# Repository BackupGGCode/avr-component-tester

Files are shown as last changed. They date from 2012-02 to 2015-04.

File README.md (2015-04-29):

# AVR Component Tester #

### DESCRIPTION ###
We really liked the original project; so we are bringing it back as ACT. Mainly for ourselves but anyone interested is welcome to build there own.

It is an AVR Atmega based electronic components tester based on the original _AVR Transistor Tester by Markus Frejek_. Its a completely open project, feel free to use the content on this Google code page in any way you like; as long as it follows the same or stricter guidelines then the original.

At the moment there is not much different then the original; other then we took away the multi-language (we will keep the strings editable for anyone interested in changing the language themselves) and only changed a few small items. Thats only because we are still awaiting our latest PCBs which includes onboard ISP header, broken out UART, and broken out un-used pins for future functionality.

Only reason I made this page was to store our updates to a public SVN.

Also see my [readme](https://github.com/BackupGGCode/avr-component-tester/blob/master/README) file.

---

### ACKNOWLEDGE ###
_This is a project based on the original_

_AVR Transistor Tester_
_by Markus Frejek_
_http://www.mikrocontroller.net/articles/AVR-Transistortester_

---

&lt;brentbxr&gt;

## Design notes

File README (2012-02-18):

The firmware was specificly designed to on an Atmega328p but really; 
any 28pin atmega 8k and up will work; and as long as your utilizing 
winavr just make sure you include its IO header file; you should be 
able to upload the source no problem. Ensure to double check the 
pinout and make changes as needed.

At some point I will most likly include differnt pre-compiled files 
for multiple atmega's for the public, depending on if there is any 
demand at all. Most likly there will be none, as its really just a 
personal project.

I also have some left-over PCBs; so if your interested just contact
BrentBXR and I might be able to mail you one. As long as you promise 
to build it up, and enjoy it. I wont send somone a PCB just so they 
can have a PCB laying around...

Thanks -BrentBXR [@gmail]

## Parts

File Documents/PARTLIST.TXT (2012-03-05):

AVR Component Tester [v1.0]
SVN: http://code.google.com/p/avr-component-tester/
Project with BrentBXR and MickM

--------------------------------------------------------------------------------------
======================================================================================
--------------------------------------------------------------------------------------

Partlist
Exported from 2-6-2012-b (2).sch at 3/1/2012 9:00:39 PM

Part        Value          Device          Package       Library                 Sheet

9V-DC-IN                   PINHD-1X2       1X02          pinhead                 1
C1          100n           C-US025-030X050 C025-030X050  rcl                     1
C2          100nF          C-US025-030X050 C025-030X050  rcl                     1
C3          100n           C-US025-030X050 C025-030X050  rcl                     1
C4          100n           C-US025-030X050 C025-030X050  rcl                     1
C5          100n           C-US025-030X050 C025-030X050  rcl                     1
C6          100uF          CPOL-USE2-5     E2-5          rcl                     1
D1          1N5817-B       1N5817-B        DO41-7.6      diode                   1
D2          5V1            BZX55           DO35Z10       diode                   1
IC1         MEGA328p       MEGA328-P       DIP28         atmel                   1
IC2         7805L          78LXX           78LXX         v-reg                   1
LCDHD44870  TUXGR_16X2_R2  TUXGR_16X2_R2   TUXGR_16X2_R2 display-lcd             1
LED1        LED            LED3MM          LED3MM        led                     1
PWR         LED            LED3MM          LED3MM        led                     1
Q1          BC547 [NPN]    BC547           SOT54A        transistor-small-signal 1
Q2          BC547 [NPN]    BC547           SOT54A        transistor-small-signal 1
Q3          BC557 [PNP]    BC557           TO92          transistor-pnp          1
R1          680           R-US_0204/7     0204/7        rcl                     1
R2          470K           R-US_0204/7     0204/7        rcl                     1
R3          680R           R-US_0204/7     0204/7        rcl                     1
R4          470K           R-US_0204/7     0204/7        rcl                     1
R5          680R           R-US_0204/7     0204/7        rcl                     1
R6          470K           R-US_0204/7     0204/7        rcl                     1
R7          27k            R-US_0204/7     0204/7        rcl                     1
R8          27K            R-US_0204/7     0204/7        rcl                     1
R9          100K           R-US_0204/7     0204/7        rcl                     1
R10         33K            R-US_0204/7     0204/7        rcl                     1
R11         10K            TRIM_EU-CA9V    CA9V          pot                     1
R12         10K            R-US_0204/7     0204/7        rcl                     1
R13         10K            R-US_0204/7     0204/7        rcl                     1
R15         150R           R-US_0204/7     0204/7        rcl                     1
R21         3K3            R-US_0204/7     0204/7        rcl                     1
R22         680R           R-US_0204/7     0204/7        rcl                     1

Notice:
For the most part the parts are not part # specific. Transistors just need to be the
correct type (NPN or PNP); decoupling caps can change; trimpot; and so on...

For best results use a military grade 1% resistors for the probes which are:
   
       750  Ohm   x3
       500 kOhm   x3

                                                                     - Brent Reamer
                                                                       aka BrentBXR

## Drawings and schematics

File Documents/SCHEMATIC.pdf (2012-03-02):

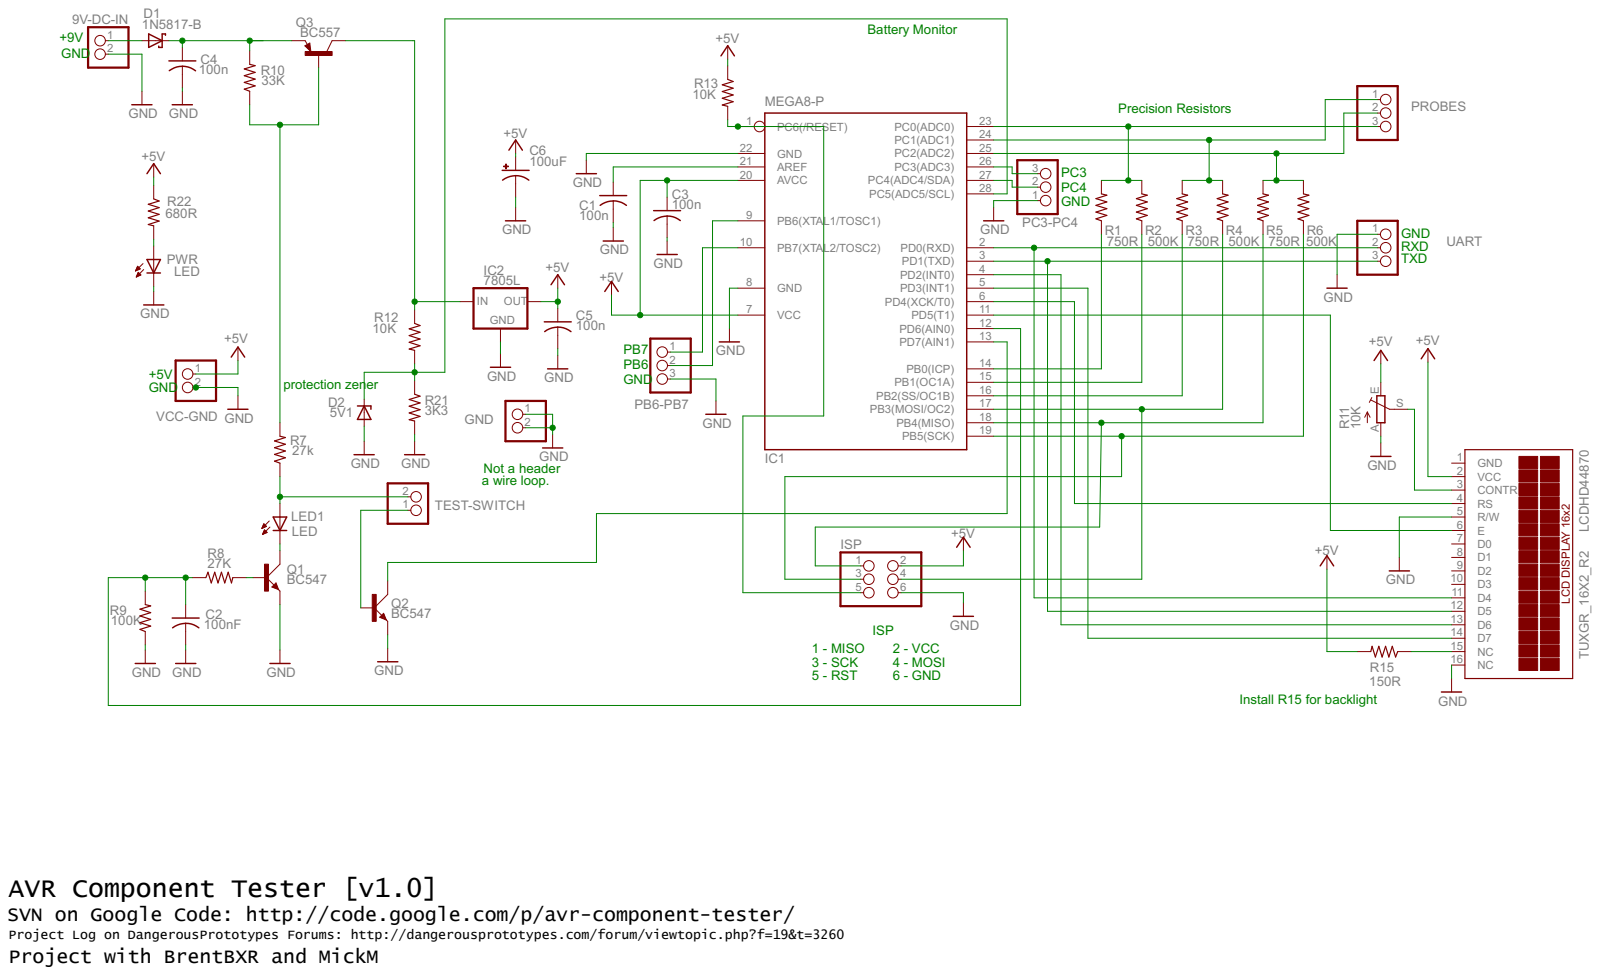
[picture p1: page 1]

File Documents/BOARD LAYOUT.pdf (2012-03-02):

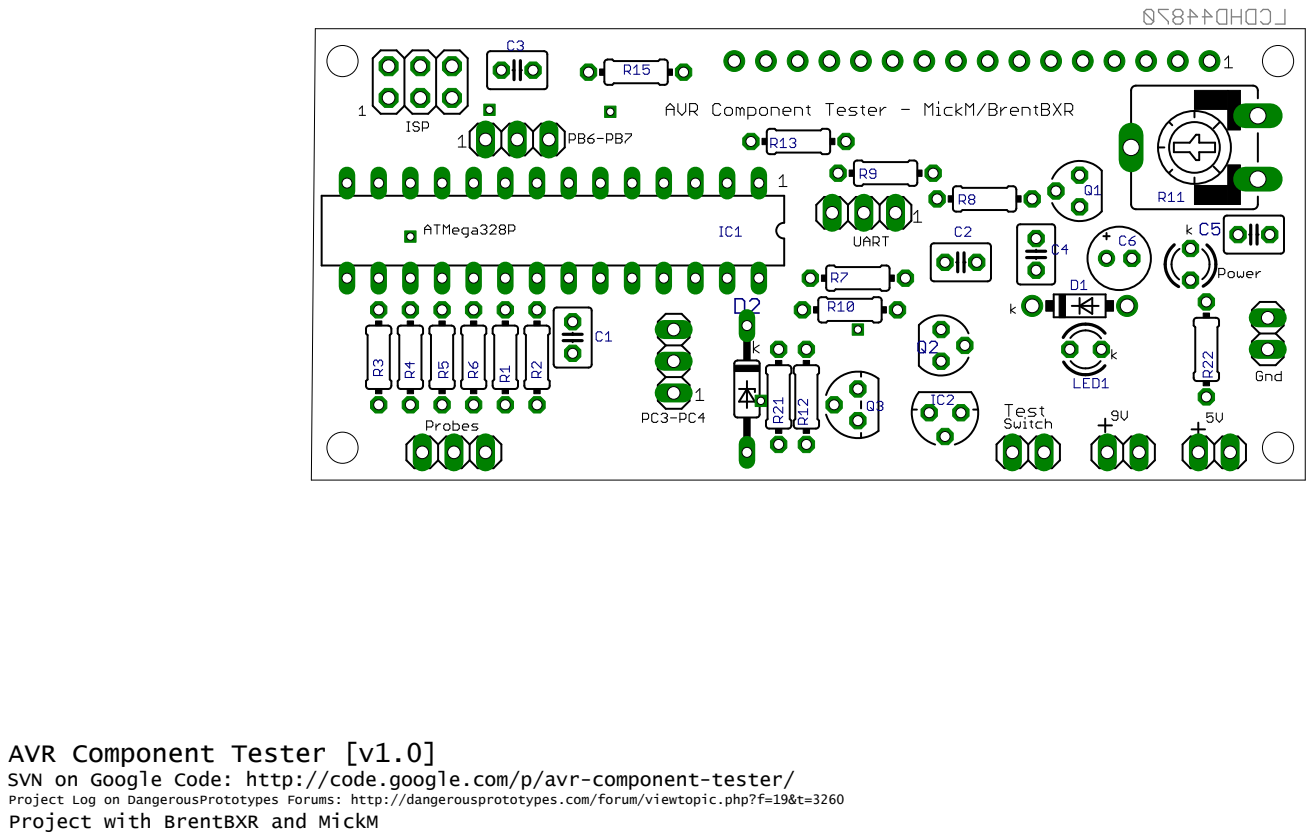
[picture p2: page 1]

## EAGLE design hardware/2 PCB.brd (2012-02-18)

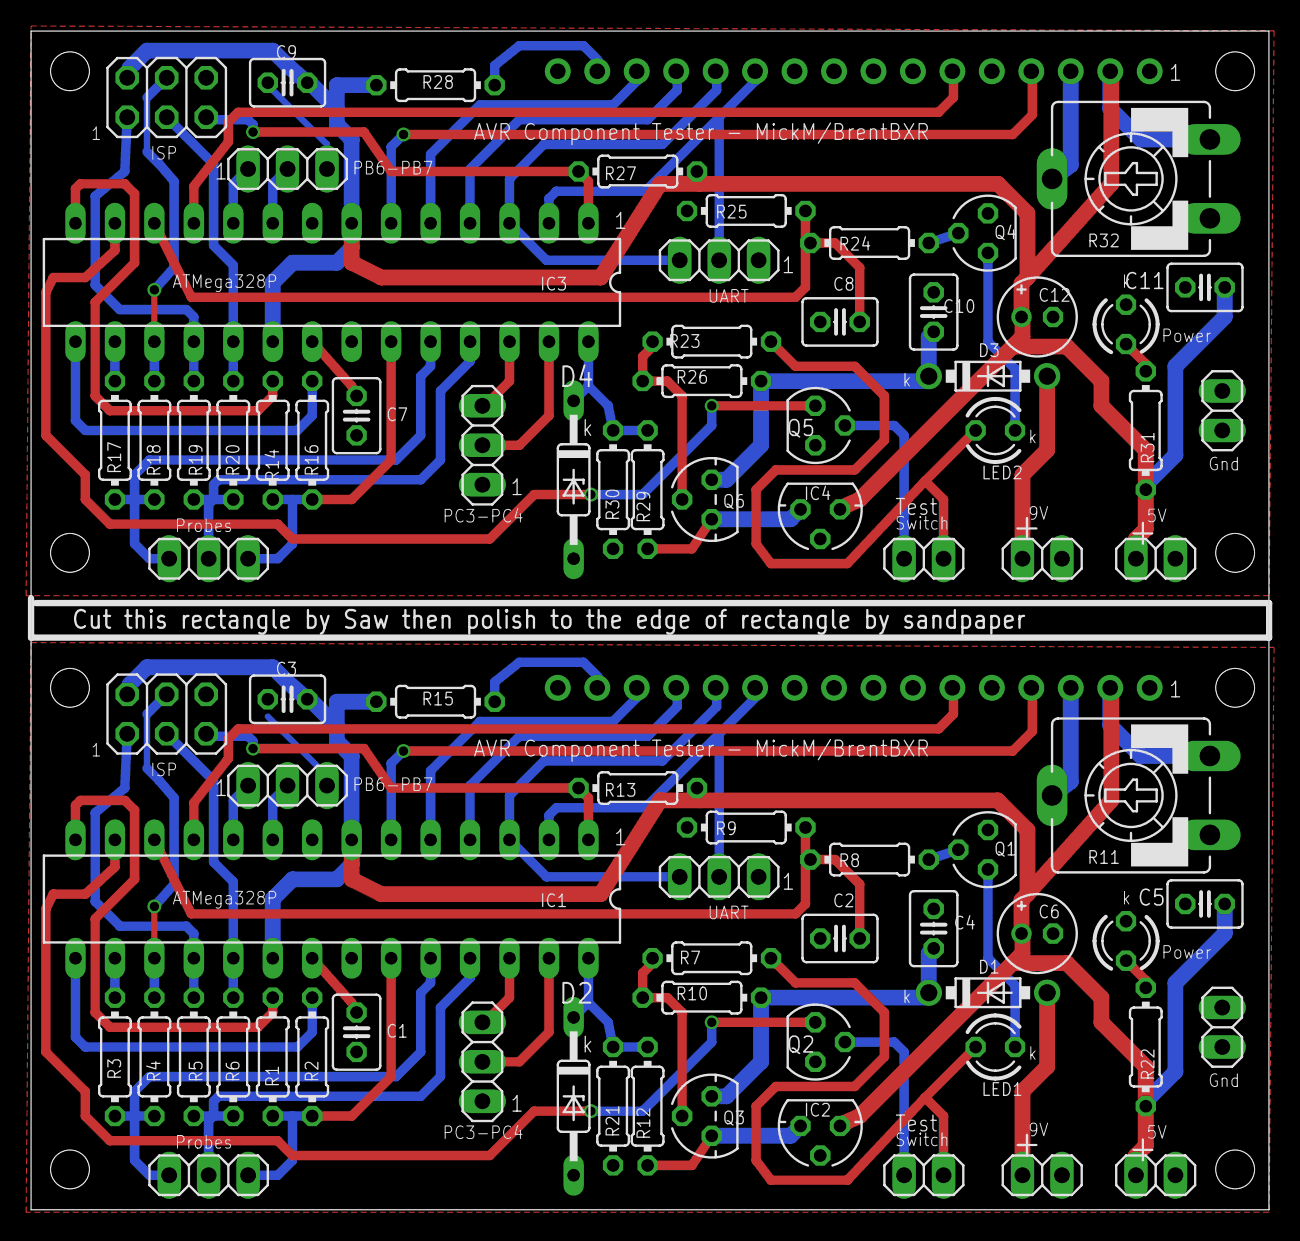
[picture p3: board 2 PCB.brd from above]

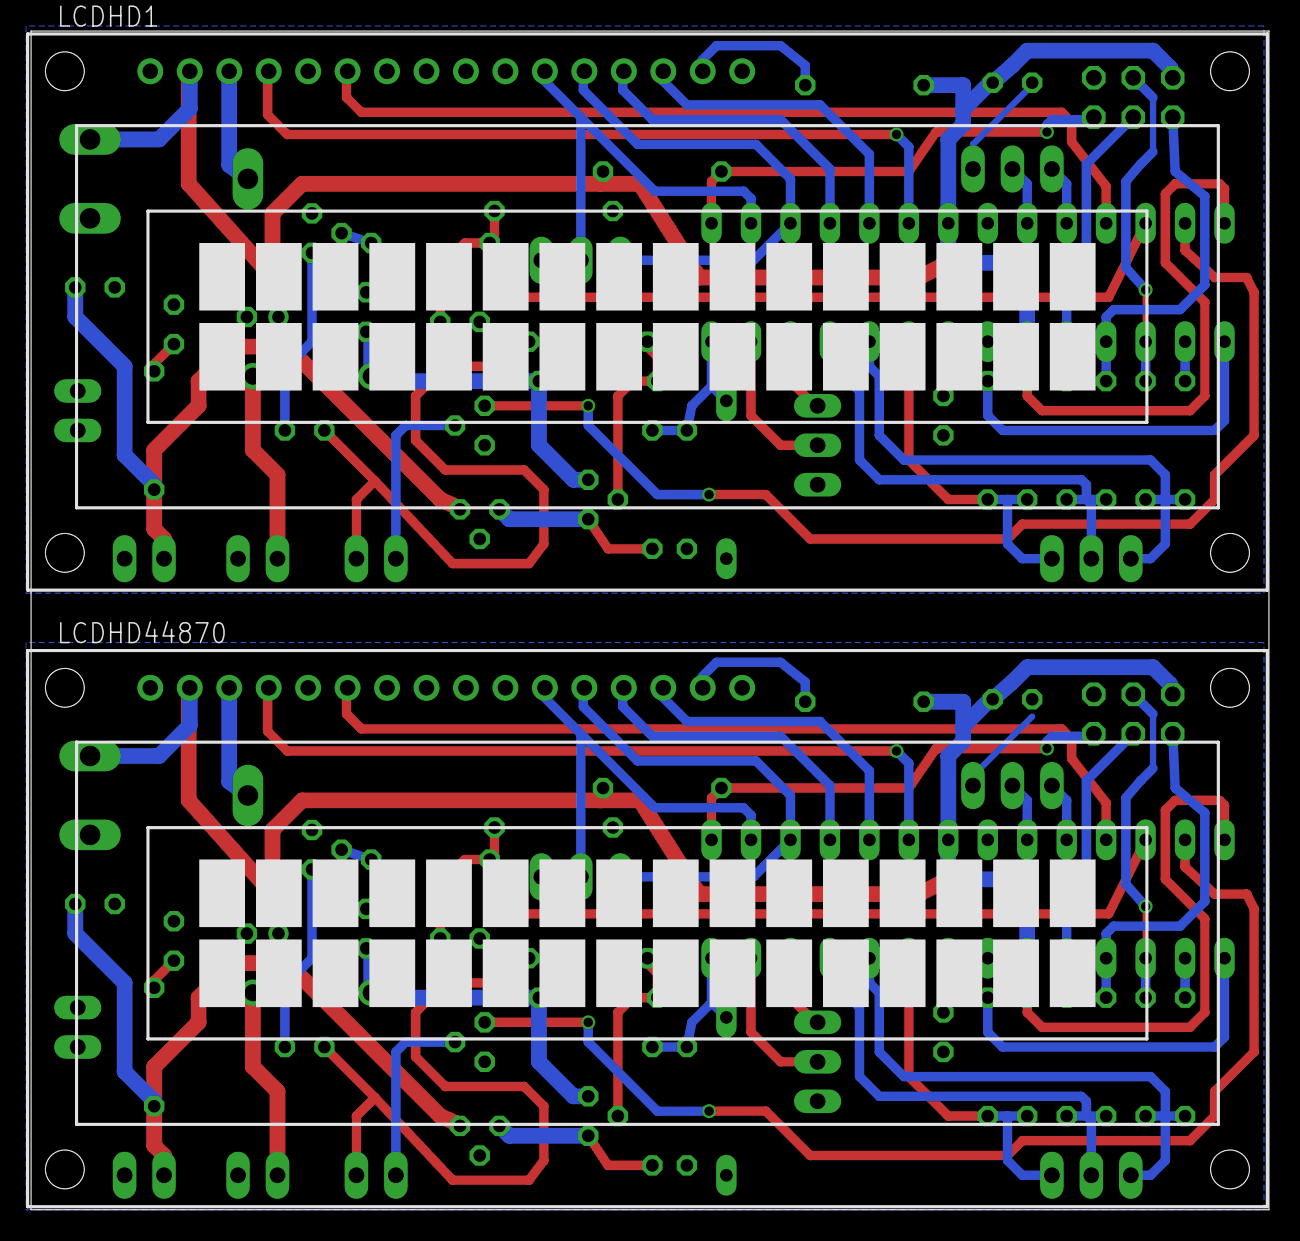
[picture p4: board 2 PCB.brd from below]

Board: 2 copper layers, 79.7 x 75.9 mm, 82 parts (2 on the bottom side), 74 nets.

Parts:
9V-DC-IN, 9V-DC-IN1: 1X02
C1, C3, C4, C5, C7, C9, C10, C11: 100n; C025-030X050
C2, C8: 100nF; C025-030X050
C6, C12: 100uF; E2-5
D1, D3: 1N5817-B; DO41-7.6
D2, D4: 5V1; DO35Z10
GND, GND1: 1X02
IC1, IC3: MEGA8-P; DIL28-3
IC2, IC4: 7805L; 78LXX
ISP, ISP1: 2X03
LCDHD1, LCDHD44870: TUXGR_16X2_R2
LED1, LED2: LED; LED3MM
PB6-PB1, PB6-PB7: 1X03
PC3-PC1, PC3-PC4: 1X03
PROBES, PROBES1: 1X03
PWR, PWR1: LED; LED3MM
Q1, Q2, Q4, Q5: BC547; SOT54A
Q3, Q6: BC557; TO92
R1, R3, R5, R14, R17, R19: 750R; 0204/7
R2, R4, R6, R16, R18, R20: 500K; 0204/7
R7, R23: 27k; 0204/7
R8, R24: 27K; 0204/7
R9, R25: 100K; 0204/7
R10, R26: 33K; 0204/7
R11, R32: 10K; CA9V
R12, R13, R27, R29: 10K; 0204/7
R15, R28: 150R; 0204/7
R21, R30: 3K3; 0204/7
R22, R31: 680R; 0204/7
TEST-SWITCH, TEST-SWITCH1: 1X02
UART, UART1: 1X03
VCC-GND, VCC-GND1: 1X02

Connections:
+5V: C3.1, C5.1, C6.+, IC1.7, IC1.20, IC2.OUT, ISP.2, LCDHD44870.2, R11.E, R13.1, R15.2, R22.1, VCC-GND.1
+5V1: C9.1, C11.1, C12.+, IC3.7, IC3.20, IC4.OUT, ISP1.2, LCDHD1.2, R27.1, R28.2, R31.1, R32.E, VCC-GND1.1
BAT-MON: D2.C, IC1.28, R12.2, R21.1
BAT-MON1: D4.C, IC3.28, R29.2, R30.1
GND: 9V-DC-IN.2, C1.2, C2.2, C3.2, C4.2, C5.2, C6.-, D2.A, GND.1, GND.2, IC1.8, IC1.22, IC2.GND, ISP.6, LCDHD44870.1, LCDHD44870.5, LCDHD44870.16, PB6-PB7.3, PC3-PC4.1, PWR.K, Q1.E, Q2.E, R9.1, R11.A, R21.2, UART.1, VCC-GND.2
GND1: 9V-DC-IN1.2, C7.2, C8.2, C9.2, C10.2, C11.2, C12.-, D4.A, GND1.1, GND1.2, IC3.8, IC3.22, IC4.GND, ISP1.6, LCDHD1.1, LCDHD1.5, LCDHD1.16, PB6-PB1.3, PC3-PC1.1, PWR1.K, Q4.E, Q5.E, R25.1, R30.2, R32.A, UART1.1, VCC-GND1.2
MISO: IC1.18, ISP.1, R5.1
MISO1: IC3.18, ISP1.1, R19.1
MOSI: IC1.17, ISP.4, R4.1
MOSI1: IC3.17, ISP1.4, R18.1
unnamed: IC2.IN, Q3.3, R12.1
unnamed: 9V-DC-IN.1, D1.A
unnamed: IC1.23, PROBES.3, R1.2, R2.2
unnamed: IC1.13, Q2.C
unnamed: IC1.25, PROBES.2, R5.2, R6.2
unnamed: IC1.14, R1.1
unnamed: IC1.15, R2.1
unnamed: IC1.16, R3.1
unnamed: PWR.A, R22.2
unnamed: IC3.23, PROBES1.3, R14.2, R16.2
unnamed: IC3.14, R14.1
unnamed: Q3.2, R7.2, R10.1
unnamed: IC1.6, LCDHD44870.4
unnamed: IC3.15, R16.1
unnamed: IC1.24, PROBES.1, R3.2, R4.2
unnamed: Q1.B, R8.2
unnamed: IC3.16, R17.1
unnamed: IC3.24, PROBES1.1, R17.2, R18.2
unnamed: IC1.9, PB6-PB7.2
unnamed: LED1.A, R7.1, TEST-SWITCH.2
unnamed: LED1.K, Q1.C
unnamed: Q2.B, TEST-SWITCH.1
unnamed: C2.1, IC1.12, R8.1, R9.2
unnamed: IC1.11, LCDHD44870.6
unnamed: Q6.2, R23.2, R26.1
unnamed: IC1.4, LCDHD44870.13
unnamed: IC1.5, LCDHD44870.14
unnamed: LCDHD44870.3, R11.S
unnamed: C1.1, IC1.21
unnamed: IC1.10, PB6-PB7.1
unnamed: LCDHD44870.15, R15.1
unnamed: Q4.B, R24.2
unnamed: C4.1, D1.C, Q3.1, R10.2
unnamed: IC1.26, PC3-PC4.3
unnamed: LED2.A, R23.1, TEST-SWITCH1.2
unnamed: LED2.K, Q4.C
unnamed: IC1.27, PC3-PC4.2
unnamed: Q5.B, TEST-SWITCH1.1
unnamed: IC3.6, LCDHD1.4
unnamed: IC3.4, LCDHD1.13
unnamed: IC3.5, LCDHD1.14
unnamed: IC3.11, LCDHD1.6
unnamed: LCDHD1.15, R28.1
unnamed: C10.1, D3.C, Q6.1, R26.2
unnamed: LCDHD1.3, R32.S
unnamed: 9V-DC-IN1.1, D3.A
unnamed: C7.1, IC3.21
unnamed: C8.1, IC3.12, R24.1, R25.2
unnamed: IC4.IN, Q6.3, R29.1
unnamed: IC3.26, PC3-PC1.3
unnamed: IC3.27, PC3-PC1.2
unnamed: IC3.9, PB6-PB1.2
unnamed: IC3.10, PB6-PB1.1
unnamed: IC3.25, PROBES1.2, R19.2, R20.2
unnamed: PWR1.A, R31.2
unnamed: IC3.13, Q5.C
RST: IC1.1, ISP.5, R13.2
RST1: IC3.1, ISP1.5, R27.2
RXD: IC1.2, LCDHD44870.11, UART.2
RXD1: IC3.2, LCDHD1.11, UART1.2
SCK: IC1.19, ISP.3, R6.1
SCK1: IC3.19, ISP1.3, R20.1
TXD: IC1.3, LCDHD44870.12, UART.3
TXD1: IC3.3, LCDHD1.12, UART1.3

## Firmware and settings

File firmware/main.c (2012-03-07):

/*

    ///////////////////////////////////////////////////////
   ///////////////// AVR Component Tester ////////////////
  //////////////////    Version 1 beta    ///////////////
 ///////////////////////////////////////////////////////

 AVR Component Tester
 Version 1.0 BETA

 This project is based on the original 'AVR Transistor Tester' and will be
 modified for a small group of people interested in expanding this project.
 The original project can be found:
 
 http://www.mikrocontroller.net/articles/AVR-Transistortester
 
 This new project (ACT for short) does not have its own website; but it does
 have its own google project page which includes news, wiki, bug tracking,
 and a publicly viewable SVN; where you can always find the latest source
 files and other resources such as: Schematics, PCB files; and even pre-
 compiled gerbers, if you want to get your own PCB(s) designed. The gerbers
 are already completed and designed to work with SEEED Studio's PCB rules and
 formats. See www.seeedstudios.com for more information on there 'Fusion PCB
 service'.

 Main Project Developers:
 BrentBXR (@Gmail.com)
 MickM
 
 We also have a related forum thread at DangerousPrototypes, there you can see
 where it all started, and where we are now with this project. Find it here:
 
 http://dangerousprototypes.com/forum/viewtopic.php?f=19&t=3260
 
 This is a open hardware project; which means everything about it from the source
 files, down to the schematics and pcb files are all open source and public domain
 you are welcome to use, modify, sell, or anything without issue. It is common
 curtosy to atleast let us know what your doing with our project if you use it.
 it is also common that if you decide to replicate and sell; that you atleast tell
 us... that said you dont have to tell us anything :P
 
                                                                   [BrentBXR]
*/

#include <avr/io.h>
#include "lcd-routines.h"
#include <util/delay.h>
#include <avr/sleep.h>
#include <stdlib.h>
#include <string.h>
#include <avr/eeprom.h>
#include <avr/wdt.h>
#include <math.h>

#include "settings.h"

// *########################################################################################

	// Initial Configuration
	
	uint8_t CapTestMode 			EEMEM 	= V_CAPTESTMODE;	
	
	unsigned int F_VER 				EEMEM 	= _FIRMWARE_VERSION_;
	unsigned int F_REV 				EEMEM 	= _FIRMWARE_REVISION_;
	unsigned int H_REV 				EEMEM 	= _HARDWARE_REVISION_;

	unsigned int R_L_VAL 			EEMEM 	= SMALL_R_VALUE;
	unsigned int R_H_VAL 			EEMEM 	= LARGE_R_VALUE;
	
	unsigned int H_CAPACITY_FACTOR 	EEMEM = SMALL_CAP_VALUE;
	unsigned int L_CAPACITY_FACTOR 	EEMEM = LARGE_CAP_VALUE;


// *########################################################################################

	// Words, messages, and strings:        
	
	
	unsigned char StartupMessage[]	EEMEM = "ACT v1.2   ";
	unsigned char BatMode[] 		EEMEM = "[BAT]";
	unsigned char PwrMode[]			EEMEM = "[PWR]";
	unsigned char TestRunning[]     EEMEM = "Testing   ->";
	unsigned char TestCapV[]		EEMEM = "Measuring ->";
	unsigned char Bat[]             EEMEM = "Battery ";
	unsigned char BatWeak[]         EEMEM = "weak";
	unsigned char BatEmpty[]        EEMEM = "empty!";

	unsigned char TestFailed1[]     EEMEM = "Unknown, Damaged";
	unsigned char TestFailed2[]     EEMEM = "or Nothing found";

	unsigned char BadResult1[]		EEMEM = " Part's Unknown";
	unsigned char BadResult2[]		EEMEM = " or Damaged: ";

	unsigned char TestTimedOut[] 	EEMEM = "Timeout!";
	
	// Components
	unsigned char Diode[]           EEMEM = "Diode: ";
	unsigned char DualDiode[]       EEMEM = "Double diode ";
	unsigned char TwoDiodes[]       EEMEM = "2 diodes";
	unsigned char Antiparallel[]    EEMEM = "anti-parallel";
	unsigned char Resistor[] 		EEMEM = "Resistor: ";
	unsigned char Capacitor[] 		EEMEM = "Capacitor: ";
	unsigned char InSeries[]        EEMEM = "serial A=";
	unsigned char Triac[]           EEMEM = "Triac";
	unsigned char Thyristor[]       EEMEM = "Thyristor";

	// Codes and Values
	unsigned char K1[]          EEMEM = ";C1=";
	unsigned char K2[]          EEMEM = ";C2=";
	unsigned char GAK[]         EEMEM = "GAC=";
	unsigned char NextK[]       EEMEM = ";C=";
	unsigned char K[]           EEMEM = "C=";
	unsigned char mosfet[]  	EEMEM = "-MOS";
	unsigned char emode[]   	EEMEM = "-E";
	unsigned char dmode[]   	EEMEM = "-D";
	unsigned char jfet[]    	EEMEM = "-JFET";
	unsigned char A1[]      	EEMEM = ";A1=";
	unsigned char A2[]      	EEMEM = ";A2=";
	unsigned char GateCap[] 	EEMEM = " C=";
	unsigned char hfestr[]  	EEMEM = "hFE=";
	unsigned char NPN[]     	EEMEM = "NPN";
	unsigned char PNP[]     	EEMEM = "PNP";
	unsigned char bstr[]    	EEMEM = " B=";
	unsigned char cstr[]    	EEMEM = ";C=";
	unsigned char estr[]    	EEMEM = ";E=";
	unsigned char gds[]     	EEMEM = "GDS=";
	unsigned char Uf[]      	EEMEM = "Uf=";
	unsigned char vt[]      	EEMEM = "Vt=";
	unsigned char mV[]      	EEMEM = "mV";
	unsigned char Anode[]   	EEMEM = "A=";
	unsigned char Gate[]    	EEMEM = "G=";
	unsigned char CA[]      	EEMEM = "CA";
	unsigned char CC[]     		EEMEM = "CC";

	// LCD Icons
	unsigned char DiodeIcon[] EEMEM = {4,31,31,14,14,4,31,4,0};	// Diode icon

struct Diode {
	uint8_t Anode;
	uint8_t Cathode;
	int Voltage;
};
									// Function prototypes

void 			CheckPins			(uint8_t HighPin, uint8_t LowPin, uint8_t TristatePin);
void 			DischargePin		(uint8_t PinToDischarge, uint8_t DischargeDirection);
unsigned int 	ReadADC				(uint8_t mux);
void 			lcd_show_format_cap	(char outval[], uint8_t strlength, uint8_t CommaPos);
void 			ReadCapacity		(uint8_t HighPin, uint8_t LowPin);		


volatile unsigned int PowerMode=PWR_5V;


struct 			Diode diodes[6];

uint8_t 		NumOfDiodes;
uint8_t 		b;						// pins of transistor
uint8_t 		c;						// pins of transistor
uint8_t 		e;						// pins of transistor
unsigned long 	lhfe;					// Amplification factor
uint8_t 		PartReady;				// Device recognized, Transistor, FET, Triac
unsigned int 	hfe[2];					// Amplification factors
unsigned int 	uBE[2];					// B-E Covering for transistors
uint8_t 		PartMode;				// See defines PART_MODE_
uint8_t 		tmpval;
uint8_t 		tmpval2;
uint8_t 		ra;						// Resistance pin
uint8_t 		rb;						// Resistance pin
unsigned int 	rv[2];					// Voltage drop at the resistance
unsigned int 	radcmax[2];	       		// Max ADC value (smaller than 1023, comes close but does not get to zero)
uint8_t 		ca;						// Condenser-Pins
uint8_t 		cb;						// Condenser-Pins
uint8_t 		cp1;					// Testing condenser pins, if measurement for individual pins selected
uint8_t 		cp2;					// Testing condenser pins, if measurement for individual pins sel
uint8_t 		ctmode;					// Condenser test mode
unsigned long 	cv;
uint8_t 		tmpPartFound;			// temp found Device, used for Resistor
uint8_t 		PartFound;				// the found Device numeric ID see defines PART_
char 			outval[8];
unsigned int 	adcv[4];
unsigned int 	gthvoltage;				// Gate threshold voltage
char 			outval2[6];

#ifdef ENABLE_PIN_ALIAS
uint8_t GetPinAlias(uint8_t nPin)				// GetPinAlias allows the user to define his own
{												// alias for each pin #; defined in 'settings.h'
   switch(nPin) {
      case (unsigned char)'1':
         nPin = PIN1_ALIAS;
         break;
      case (unsigned char)'2':
         nPin = PIN2_ALIAS;
         break;
      case (unsigned char)'3':
         nPin = PIN3_ALIAS;
         break;
   }
   return nPin;
}
#else
	#define GetPinAlias(x) (x)
#endif


int main(void) {

  POWER_ON();											// Turn the regulator ON
  PWRMODE_SETUP();										// Setup PWRMODE jumper input
  lcd_init();											// init LCD
  
  uint8_t tmp;
  ADCSRA = (1<<ADEN) | (1<<ADPS1) | (1<<ADPS0);		// Enable ADC, set Prescale to 8
  
  unsigned int rhval = eeprom_read_word(&R_H_VAL);		// R_H
  unsigned int rlval = eeprom_read_word(&R_L_VAL);		// R_L
  
  ctmode = eeprom_read_byte(&CapTestMode);				// Compile time choice of test modes (0x22)
  cp1 = (ctmode & 12) >> 2;							// Capacitor pin 1, DEFAULT 0
  cp2 = ctmode & 3;										// Capacitor pin 2, DEFAULT 2
  ctmode = (ctmode & 48) >> 4;							// Capacitor test mode, DEFAULT is 0x02 for all 6 cap tests.
  
  wdt_disable();										// Disable watch dog timer.
  
  if(MCU_STATUS_REG & (1<<WDRF)) {						// Examine for Watchdog RESETs That enters, if the Watchdog 2s were not put back Can occur, 
    lcd_clear();                                                    // if the program in a continuous loop " itself; tangled" has.
    lcd_eep_string(TestTimedOut);						// Message - "Timeout!"
    _delay_ms(3000);                                	// Wait 3 sec
	wdt_enable(WDTO_2S);								// Wait two seconds; if on power it will reset; on battery it will turn itself off
    while(1) {
		POWER_OFF();									// Power down in BAT mode or RESET in PWR mode
	}
  }
  
  LCDLoadCustomChar();									// Custom indication Diode symbol into LCD load
  lcd_eep_string(DiodeIcon);							// Message - diode icon
  Line1();												// jump to start of first line

start:													// re-entry point, if button is re-pressed
  #ifdef WDT_enabled
    wdt_enable(WDTO_2S);								// Watchdog Timer on, 2 seconds?
  #endif

  PartFound 	= PART_NONE;							// Default all results
  tmpPartFound 	= PART_NONE;							//		  "    " 
  NumOfDiodes 	= 0;									//			||
  PartReady 	= 0;									//			||
  PartMode 		= 0;									//			||
  ca 			= 0;									//			||
  cb 			= 0;									//			\/

											//	->	// Startup Message ////////////////////////////////////////
  lcd_clear();										// 
  lcd_eep_string(StartupMessage);					// LCD: ACT v#.#    [XXX]


  
											//	->	// Power selection and Battery Testing ////////////////////

  if(PWRMODE_GET()) {								// Get the PWRMODE jumper logic
	PowerMode = PWR_9V;								// Set powermode to PWR_9V
	_delay_us(250);
	
	ReadADC(5 | (1<<REFS1));						// Measure the 9V battery Supply ( - diode drop)
	hfe[0] = ReadADC(5 | (1<<REFS1));				// if in battery mode.
	
	lcd_eep_string(BatMode);						// Tell user device in BAT mode
	Line2();
	
	if (hfe[0] < BAT_WEAK) {						// Compare 9v reading with BAT_WEAK variable
		
		if(hfe[0] < BAT_DEAD) {					// If the batter is considered dead then
			lcd_eep_string(Bat);					
			lcd_eep_string(BatEmpty);				// Tell the user battery is DEAD
			_delay_ms(3000);						// Wait a bit.
			while(1) {								// Forever loop
				POWER_OFF();						// keep trying to kill the power forever.
			}
		}
		
		lcd_clear();			
		lcd_eep_string(Bat);						// Battery isnt dead; its just weak
		lcd_eep_string(BatWeak);					// tell the user; but keep testing...
		Line2();									// Start second line
	  }
  } else {
	PowerMode = PWR_5V;								// Power mode is constent v5, skip battery check.
    lcd_eep_string(PwrMode);						// Tell user we are running in PWR mode.
	Line2();
  }
 
											//	->	// Begin testing sequince. ///////////////////////////////
	
  lcd_eep_string(TestRunning);						// Tell user the testing has begun...
  
  UpdateProgress("00%");							// Progress at 00% and Testing
  
  CheckPins(TP1, TP2, TP3);							//			||
  UpdateProgress("16%");							//			\/
  
  CheckPins(TP1, TP3, TP2);							//		TESTING...
  UpdateProgress("33%");							//

  CheckPins(TP2, TP1, TP3);							//			||
  UpdateProgress("50%");							//			\/
  
  CheckPins(TP2, TP3, TP1);							//		TESTING...
  UpdateProgress("66%");							//
  
  CheckPins(TP3, TP2, TP1);							//			||
  UpdateProgress("83%");							//			\/
  
  CheckPins(TP3, TP1, TP2);							//	   Almost there!
  UpdateProgress("99%");							// Testing Completed or 99%
  

//---------------------------------------------CAPACITOR---------------------------------------
									// Separate measurement to the test on condenser
  if(((PartFound == PART_NONE) || (PartFound == PART_RESISTOR) || (PartFound == PART_DIODE)) && (ctmode > 0)) {
									// Condenser unload; otherwise possibly no measurement is possible
    R_PORT = 0;
    R_DDR = (1<<(TP1 * 2)) | (1<<(TP2 * 2)) | (1<<(TP3 * 2));
    _delay_ms(10);
    R_DDR = 0;

    if(ctmode == NORMAL_CAP_TESTS) {					// see if we want to do all 6 Cap Tests
      ReadCapacity(cp1, cp2);						// No - just read the pins both ways.
      ReadCapacity(cp2, cp1);
    } else {								// DEFAULT ctmode == 0x02  to do all tests
	Line2();
	lcd_eep_string(TestCapV);
	UpdateProgress("00%");
	
	ReadCapacity(TP3, TP1);
	UpdateProgress("16%");
	
	ReadCapacity(TP3, TP2);
	UpdateProgress("33%");
	
	ReadCapacity(TP2, TP3);
	UpdateProgress("50%");
	
	ReadCapacity(TP2, TP1);
	UpdateProgress("66%");
	
	ReadCapacity(TP1, TP3);
	UpdateProgress("83%");
	
	ReadCapacity(TP1, TP2);
	UpdateProgress("99%");
      }
   }

  lcd_clear();								// Finished, now evaluate, the results

//---------------------------------------------DIODE------------------------------------------------  
  if(PartFound == PART_DIODE) {
    if(NumOfDiodes == 1) {						// Standard-Diode
      lcd_eep_string(Diode);						// Message - "Diode: "
      lcd_eep_string(Anode);						// Message - "A="
      lcd_data(GetPinAlias(diodes[0].Anode + ASCII_1));				// Display 1, 2, or 3
      lcd_eep_string(NextK);						// Message - ";C="
      lcd_data(GetPinAlias(diodes[0].Cathode + ASCII_1));				// Display 1, 2, or 3
      Line2();								// Start second line
      lcd_eep_string(Uf);						// Message - "Uf="
      lcd_string(itoa(diodes[0].Voltage, outval, 10));
      lcd_eep_string(mV);						// Message - "mV"
      goto end;
    } else if(NumOfDiodes == 2) {					// dual diode
	if(diodes[0].Anode == diodes[1].Anode) {			// Common Anode
	  lcd_eep_string(DualDiode);					// Message - "Double diode €"
	  lcd_eep_string(CA);						// Message - "CA"
	  Line2();							// Start second line
	  lcd_eep_string(Anode);					// Message - "A="
	  lcd_data(GetPinAlias(diodes[0].Anode + ASCII_1));				// Display 1, 2, or 3
	  lcd_eep_string(K1);						// Message - ";C1="
	  lcd_data(GetPinAlias(diodes[0].Cathode + ASCII_1));				// Display 1, 2, or 3
	  lcd_eep_string(K2);						// Message - ";C2="
	  lcd_data(GetPinAlias(diodes[1].Cathode + ASCII_1));			// Display 1, 2, or 3
	  goto end;
	} else if(diodes[0].Cathode == diodes[1].Cathode) {		// Common Cathode
	    lcd_eep_string(DualDiode);					// Message - "Double diode €"
	    lcd_eep_string(CC);						// Message - "CC"
	    Line2(); 							// Start second line
	    lcd_eep_string(K);						// Message - "C="
	    lcd_data(GetPinAlias(diodes[0].Cathode + ASCII_1));			// Display 1, 2, or 3
	    lcd_eep_string(A1);						// Message - ";A1="
	    lcd_data(GetPinAlias(diodes[0].Anode + ASCII_1));			// Display 1, 2, or 3
	    lcd_eep_string(A2);						// Message - ";A2="
	    lcd_data(GetPinAlias(diodes[1].Anode + ASCII_1));			// Display 1, 2, or 3
	    goto end;
	  } else if ((diodes[0].Cathode == diodes[1].Anode) && \
		     (diodes[1].Cathode == diodes[0].Anode)) {		// Antiparallel
	      lcd_eep_string(TwoDiodes);				// Message - "2 diodes"
	      Line2(); 							// Start second line
	      lcd_eep_string(Antiparallel);				// Message - "anti-parallel"
	      goto end;
	    }
    } else if(NumOfDiodes == 3) { 					// Series connection from 2 diodes; as 3 diodes one recognizes
	b = 3;
	c = 3;
									// Check to see if it is series connection of 2 diodes.
									// But 2 cathodes, and 2 anodes must agree.
									// Then the 2 diodes are a single dual-diode.
	if((diodes[0].Anode == diodes[1].Anode) || (diodes[0].Anode == diodes[2].Anode)) 
	  b = diodes[0].Anode;

	if(diodes[1].Anode == diodes[2].Anode) 
	  b = diodes[1].Anode;

	if((diodes[0].Cathode == diodes[1].Cathode) || (diodes[0].Cathode == diodes[2].Cathode)) 
	  c = diodes[0].Cathode;

	if(diodes[1].Cathode == diodes[2].Cathode) 
	  c = diodes[1].Cathode;

	if((b<3) && (c<3)) {
	  lcd_eep_string(TwoDiodes);					// Message - "2 diodes"
	  Line2();							// Start second line
	  lcd_eep_string(InSeries);					// Message - "serial A=€€"
	  lcd_data(GetPinAlias(b + ASCII_1));					// Display 1, 2, or 3
	  lcd_eep_string(NextK);					// Message - ";C="
	  lcd_data(GetPinAlias(c + ASCII_1));					// Display 1, 2, or 3
	  goto end;
	}
      }
  } 
  	
//---------------------------------------------TRANSISTOR--------------------------------------------
    else if (PartFound == PART_TRANSISTOR) {
      if(PartReady == 0) {						// 2nd examination never made, e.g. a transistor with protection diode.
	hfe[1] = hfe[0];
	uBE[1] = uBE[0];
      }

      if((hfe[0]>hfe[1])) {						// If the amplification factor with the first test was higher: swap C and E
	hfe[1] = hfe[0];
	uBE[1] = uBE[0];
	tmp = c;
	c = e;
	e = tmp;
      }

      if(PartMode == PART_MODE_NPN) 
	lcd_eep_string(NPN);						// Message - "NPN"
      else 
	lcd_eep_string(PNP);						// Message - "PNP"

      lcd_eep_string(bstr);						// Message - " B="
      lcd_data(GetPinAlias(b + ASCII_1));						// Display 1, 2, or 3
      
      lcd_eep_string(cstr);						// Message - ";C="
      lcd_data(GetPinAlias(c + ASCII_1));						// Display 1, 2, or 3
      
      lcd_eep_string(estr);						// Message - ";E="
      lcd_data(GetPinAlias(e + ASCII_1));						// Display 1, 2, or 3
      
      Line2(); 								// Start second line
									// Amplification factor compute, hFE = Emitter current/base current
      lhfe = hfe[1];
      lhfe *= (((unsigned long)rhval * 100) / (unsigned long)rlval);	// 500000/750 = 666.666r
      

      if(uBE[1]<11) 
	uBE[1] = 11;

      lhfe /= uBE[1];
      hfe[1] = (unsigned int) lhfe;
      lcd_eep_string(hfestr);						// Message - "hFE="
      lcd_string(utoa(hfe[1], outval, 10));
      SetCursor(2,7);							// Cursor on line 2, character 7

      if(NumOfDiodes > 2) 						// Transistor with protection diode
	lcd_data(LCD_CHAR_DIODE);					// Diode indicate
      else
	lcd_data(' ');

      for(c=0;c<NumOfDiodes;c++) {
	if(( (diodes[c].Cathode == e) && (diodes[c].Anode == b) && \
	     (PartMode == PART_MODE_NPN)) || ((diodes[c].Anode == e) && \
	     (diodes[c].Cathode == b) && (PartMode == PART_MODE_PNP))) {
	  lcd_eep_string(Uf);						// Message - "Uf="
	  lcd_string(itoa(diodes[c].Voltage, outval, 10));
	  lcd_data('m');
	  goto end;
	}
      }

      goto end;
      } 

//---------------------------------------------FET---------------------------------------------------     
	else if (PartFound == PART_FET) {				// JFET or MOSFET
	  if(PartMode & 1)						// N-channel
	    lcd_data('N');
	  else 
	    lcd_data('P');						// P-channel

	  if((PartMode == PART_MODE_N_D_MOS) || (PartMode == PART_MODE_P_D_MOS)) {
	    lcd_eep_string(dmode);					// Message - "-D"
	    lcd_eep_string(mosfet);					// Message - "-MOS"
	    } else {
		if((PartMode == PART_MODE_N_JFET) || (PartMode == PART_MODE_P_JFET)) 
		  lcd_eep_string(jfet);					// Message - "-JFET"
		else {
		  lcd_eep_string(emode);				// Message - "-E"
		  lcd_eep_string(mosfet);				// Message - "-MOS"
		}
	    }
									// Gate capacity
	  if(PartMode < 3) {						// Enrichment MOSFET
	    lcd_eep_string(GateCap);					// Message - " C="
	    ReadCapacity(b,e);						// Measurement
	    hfe[0] = (unsigned int)cv;

	    if(hfe[0]>2) 
	      hfe[0] -= 3;

	    utoa(hfe[0], outval2, 10);
	    tmpval = strlen(outval2);
	    tmpval2 = tmpval;

	    if(tmpval>4) 
	      tmpval = 4;						// If capacity > 100nF drop fractional part to fit on the LCD

	    lcd_show_format_cap(outval2, tmpval, tmpval2);
	    lcd_data('n');
	  }

	  Line2();							// Start second line
	  lcd_eep_string(gds);						// Message - "GDS="
	  lcd_data(GetPinAlias(b + ASCII_1));					// Display 1, 2, or 3
	  lcd_data(GetPinAlias(c + ASCII_1));					// Display 1, 2, or 3
	  lcd_data(GetPinAlias(e + ASCII_1));					// Display 1, 2, or 3

	  if((NumOfDiodes > 0) && (PartMode < 3))			// MOSFET with protection diode; it gives only with enrichment FETs 
	    lcd_data(LCD_CHAR_DIODE);					// Diode indicate
	  else 
	    lcd_data(' ');						// Blank

	  if(PartMode < 3) {						// Enrichment MOSFET
	    gthvoltage=(gthvoltage/8);
	    lcd_eep_string(vt);						// Message - "Vt="
	    lcd_string(utoa(gthvoltage, outval, 10));			// Gate threshold voltage, was determined before
	    lcd_data('m');
	  }

	  goto end;


      } 

//---------------------------------------------THYRISTOR---------------------------------------------     
	else if (PartFound == PART_THYRISTOR) {
	  lcd_eep_string(Thyristor);			 		// Message - "Thyristor"
	  Line2();						 	// Start second line
	  lcd_eep_string(GAK);				 		// Message - "GAC="
	  lcd_data(GetPinAlias(b + ASCII_1));					// Display 1, 2, or 3
	  lcd_data(GetPinAlias(c + ASCII_1));					// Display 1, 2, or 3
	  lcd_data(GetPinAlias(e + ASCII_1));					// Display 1, 2, or 3
	  goto end;

	} 

//---------------------------------------------TRIAC-------------------------------------------------	
	  else if (PartFound == PART_TRIAC) {
	    lcd_eep_string(Triac);					// Message - "Triac"
	    Line2();							// Start second line
	    lcd_eep_string(Gate);					// Message - "G="
	    lcd_data(GetPinAlias(b + ASCII_1));					// Display 1, 2, or 3
	    lcd_eep_string(A1);						// Message - ";A1="
	    lcd_data(GetPinAlias(e + ASCII_1));					// Display 1, 2, or 3
	    lcd_eep_string(A2);						// Message - ";A2="
	    lcd_data(GetPinAlias(c + ASCII_1));					// Display 1, 2, or 3
	    goto end;

	  }
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

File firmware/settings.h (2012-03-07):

////////////////////////////////////////////
/////
////     AVR Component Tester
///       BrentBXR & MickM
// -----------------------------
// 
// ACT Settings Definitions ->
//     CID: 0x9938A4E
//     SID: 001
//
// $desc This file holds all the customizable settings as
//       defines. Be very carefull when editing this file
//       only modify this  file if you know what  you are
//       doing.  You  have  been  warned.
//
//


#ifndef _SETTINGS_H_ 
#define _SETTINGS_H_


	#define MCU_STATUS_REG MCUCR
	
	#define _PROJECT_NAME_ "ACT"
	#define _PROJECT_FULLNAME_ "AVR Component Tester"
	
	#define _FIRMWARE_VERSION_ 1
	#define _FIRMWARE_REVISION_ 2
	#define _HARDWARE_REVISION_ 2


//////// [ Override Pin# with Custom Alias ] ///////////////////////////////////////////////////////////////////

	//// ENABLE_PIN_ALIAS if defined then making a probe alias is enabled
	#define ENABLE_PIN_ALIAS
	
	//// Aliases /////////////////////////
	#ifdef ENABLE_PIN_ALIAS
		#define PIN1_ALIAS 'Y' // [pFLAG]
		#define PIN2_ALIAS 'B' 
		#define PIN3_ALIAS 'G'
		//#define PIN1_ALIAS '1'
		//#define PIN2_ALIAS '2'
		//#define PIN3_ALIAS '3'	
	#endif

//////// [ Override Pin# with Custom Alias ] ///////////////////////////////////////////////////////////////////

	//// LCD_SLOW_SEND if defined will put a small delay between LCD commands
	#define LCD_SLOW_SEND


//////// [ Probe and Input Registers ] /////////////////////////////////////////////////////////////////////////

	//// Defined Settings 
	#define ADC_PORT PORTC						// Use port C for A to D inputs
	#define ADC_DDR DDRC
	#define ADC_PIN PINC
	#define TP1 PC0								// AVR pin 23 probe.
	#define TP2 PC1								// AVR pin 24 probe.
	#define TP3 PC2								// AVR pin 25 probe.



//////// [ Internal Calculation Variables ] ////////////////////////////////////////////////////////////////////
	#define SMALL_CAP_VALUE 394						// 218  0xDA    Adjust for accuracy on big Caps with 750R, was 394
	#define LARGE_CAP_VALUE 283						// 167  0xA7    Adjust for accuracy, small Caps with 500K, was 283
	#define BAT_WEAK 850							// 930  0x03A2  7.7V weak battery, was 650
	#define BAT_DEAD 650							// 875  0x036B  7.2V dead Battery, was 600
	#define LARGE_R_VALUE 4700						// 
	#define SMALL_R_VALUE 680						// 
	#define ASCII_1 49								// Ascii one.
	#define ASCII_0 48								// Ascii zero.
	#define NORMAL_CAP_TESTS 1						// Just do normal Cap test, compare to CapTestMode in EEPROM, 2 to enable all
	#define HALF_ADC_RANGE 512						// midpoint of ADC
	#define MAX_ADC 1023							// Maximum ADC count
	#define WDT_enabled  							// Watchdog active for normal use, disable for debug
	
	#define V_CAPTESTMODE 0b00100010				// 34 0x22, last used EEPROM address 0x15A, Cap test type, pins to use
													// DEFAULT  0x22 = All 6 Cap Tests, 1st 0, 2nd 2


//////// [ Usfull Bit Control Defines ] ///////////////////////////////////////////////////////////////////////
	#define SETBIT(ADDRESS,BIT) (ADDRESS |= (1<<BIT)) 
	#define CLEARBIT(ADDRESS,BIT) (ADDRESS &= ~(1<<BIT)) 
	#define FLIPBIT(ADDRESS,BIT) (ADDRESS ^= (1<<BIT)) 
	#define CHECKBIT(ADDRESS,BIT) (ADDRESS & (1<<BIT)) 

	#define SETBITMASK(x,y) (x |= (y)) 
	#define CLEARBITMASK(x,y) (x &= (~y)) 
	#define FLIPBITMASK(x,y) (x ^= (y)) 
	#define CHECKBITMASK(x,y) (x & (y)) 

	#define VARFROMCOMB(x, y) x 
	#define BITFROMCOMB(x, y) y 

	#define C_SETBIT(comb) SETBIT(VARFROMCOMB(comb), BITFROMCOMB(comb)) 
	#define C_CLEARBIT(comb) CLEARBIT(VARFROMCOMB(comb), BITFROMCOMB(comb)) 
	#define C_FLIPBIT(comb) FLIPBIT(VARFROMCOMB(comb), BITFROMCOMB(comb)) 
	#define C_CHECKBIT(comb) CHECKBIT(VARFROMCOMB(comb), BITFROMCOMB(comb)) 

	#define nop()  __asm__ __volatile__("nop")
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

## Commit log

2012-02-18 Added the hardware files
    [2 PCB.brd, 2-6-2012-b.brd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]
2012-03-02 Added partslist, board and schematic pdf's
2012-03-05 Fixed the probe resistors; they where backwards and wrong values.
    [2-6-2012-b.brd, 2-6-2012-b.sch]
2012-03-05 Just added a neat little percentage shown during testing. Just for looks really but is also informational incase it gets stuck we can trace at what testing point it was stuck.
    [main.c, settings.h]
2012-03-06 Changes include: * Software UART has been removed. * lcd routines have been cleaned up and compacted * a testing percentage has been added for looks and function * the makefile has been re-developed 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
    [main.c, settings.h]
2012-03-06 Changes: * Major cleanup of settings.h * formatting main.c * created control defines (POWER_ON = turn on regulator, POWER_OFF, PWRMODE_SETUP, ...)
2012-03-07 Version 1.2 -Changes: * Fixed the messages for damaged or no parts found * Deleted useless EEPROM variables (only 30% used now) * Added two levels of percentage monitoring/stages: -> The Identifying 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
    BXR
    [main.c, settings.h]
